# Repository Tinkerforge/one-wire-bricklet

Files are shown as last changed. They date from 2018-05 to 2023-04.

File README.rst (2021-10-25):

One Wire Bricklet
=================

This repository contains the firmware source code and the hardware design
files. The documentation generator configs can be found at
https://github.com/Tinkerforge/generators

Repository Content
------------------

software/:
 * examples/: Examples for all supported languages
 * build/: Compiled files
 * src/: Source code of firmware
 * Makefile: Makefile to build project

hardware/:
 * Contains KiCad project files and additionally schematics as PDF

datasheets/:
 * Contains datasheets for sensors and complex ICs that are used

Hardware
--------

The hardware is designed with the open source EDA Suite KiCad
(http://www.kicad.org). Before you are able to open the files,
you have to install the Tinkerforge kicad-libraries
(https://github.com/Tinkerforge/kicad-libraries). You can either clone
them directly in hardware/ or clone them in a separate folder and
symlink them into hardware/
(ln -s kicad_path/kicad-libraries project_path/hardware). After that you
can open the .pro file in hardware/ with KiCad and from there view and
modify the schematics and the PCB layout.

Software
--------

If you want to do your own Brick/Bricklet firmware development we highly
recommend that you use our build environment setup script and read the
tutorial (https://www.tinkerforge.com/en/doc/Tutorials/Tutorial_Build_Environment/Tutorial.html).

To compile the C code we recommend you to install the newest GNU Arm Embedded
Toolchain (https://launchpad.net/gcc-arm-embedded/+download).
You also need to install bricklib2 (https://github.com/Tinkerforge/bricklib2).

You can either clone it directly in software/src/ or clone it in a
separate folder and symlink it into software/src/
(ln -s bricklib_path/bricklib2 project_path/software/src/). Finally make sure to
have CMake installed (http://www.cmake.org/cmake/resources/software.html).

After that you can build the firmware by invoking make in software/.
The firmware (.zbin) can then be found in software/build/ and uploaded
with brickv (click button "Flashing" on start screen).

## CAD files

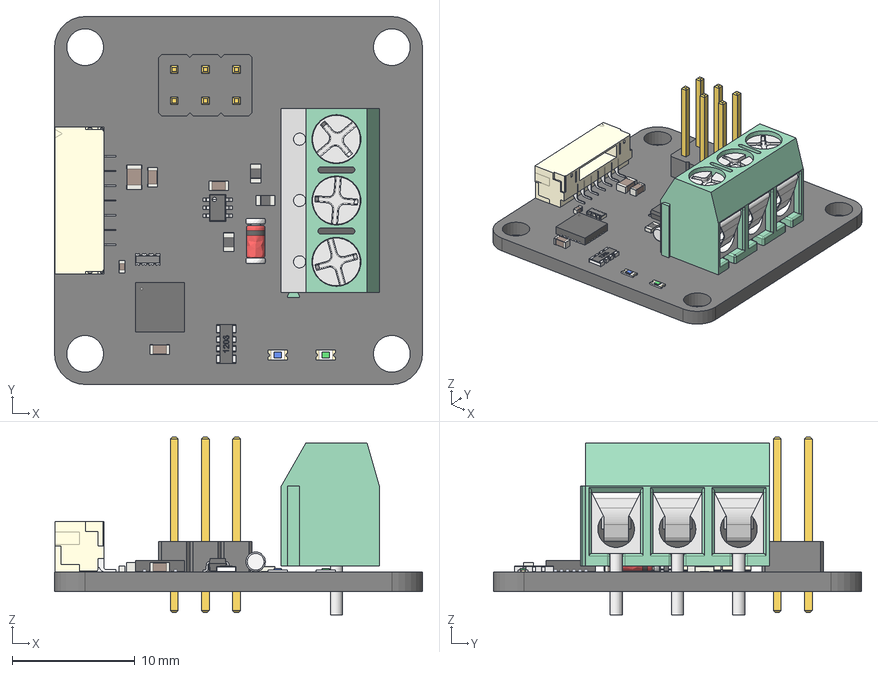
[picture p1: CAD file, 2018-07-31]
hardware/one-wire.step
30.0 x 30.0 x 14.5 mm
Pcb
QFN-24_4x4mm_Pitch0.5mm_
3er_Buchse_
User_Library-SOT363-2_
C_0805_
C_0603_
C_0603_001
D_0603_blue_
BrickletConn_7pin_
PinHeader_Straight_2x03x254mm_
R_0603_
R_0603_001
C_0603_002
R_4x0603_
C_0402_
R_0603_002
MiniMelf_

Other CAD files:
hardware/one-wire.FCStd

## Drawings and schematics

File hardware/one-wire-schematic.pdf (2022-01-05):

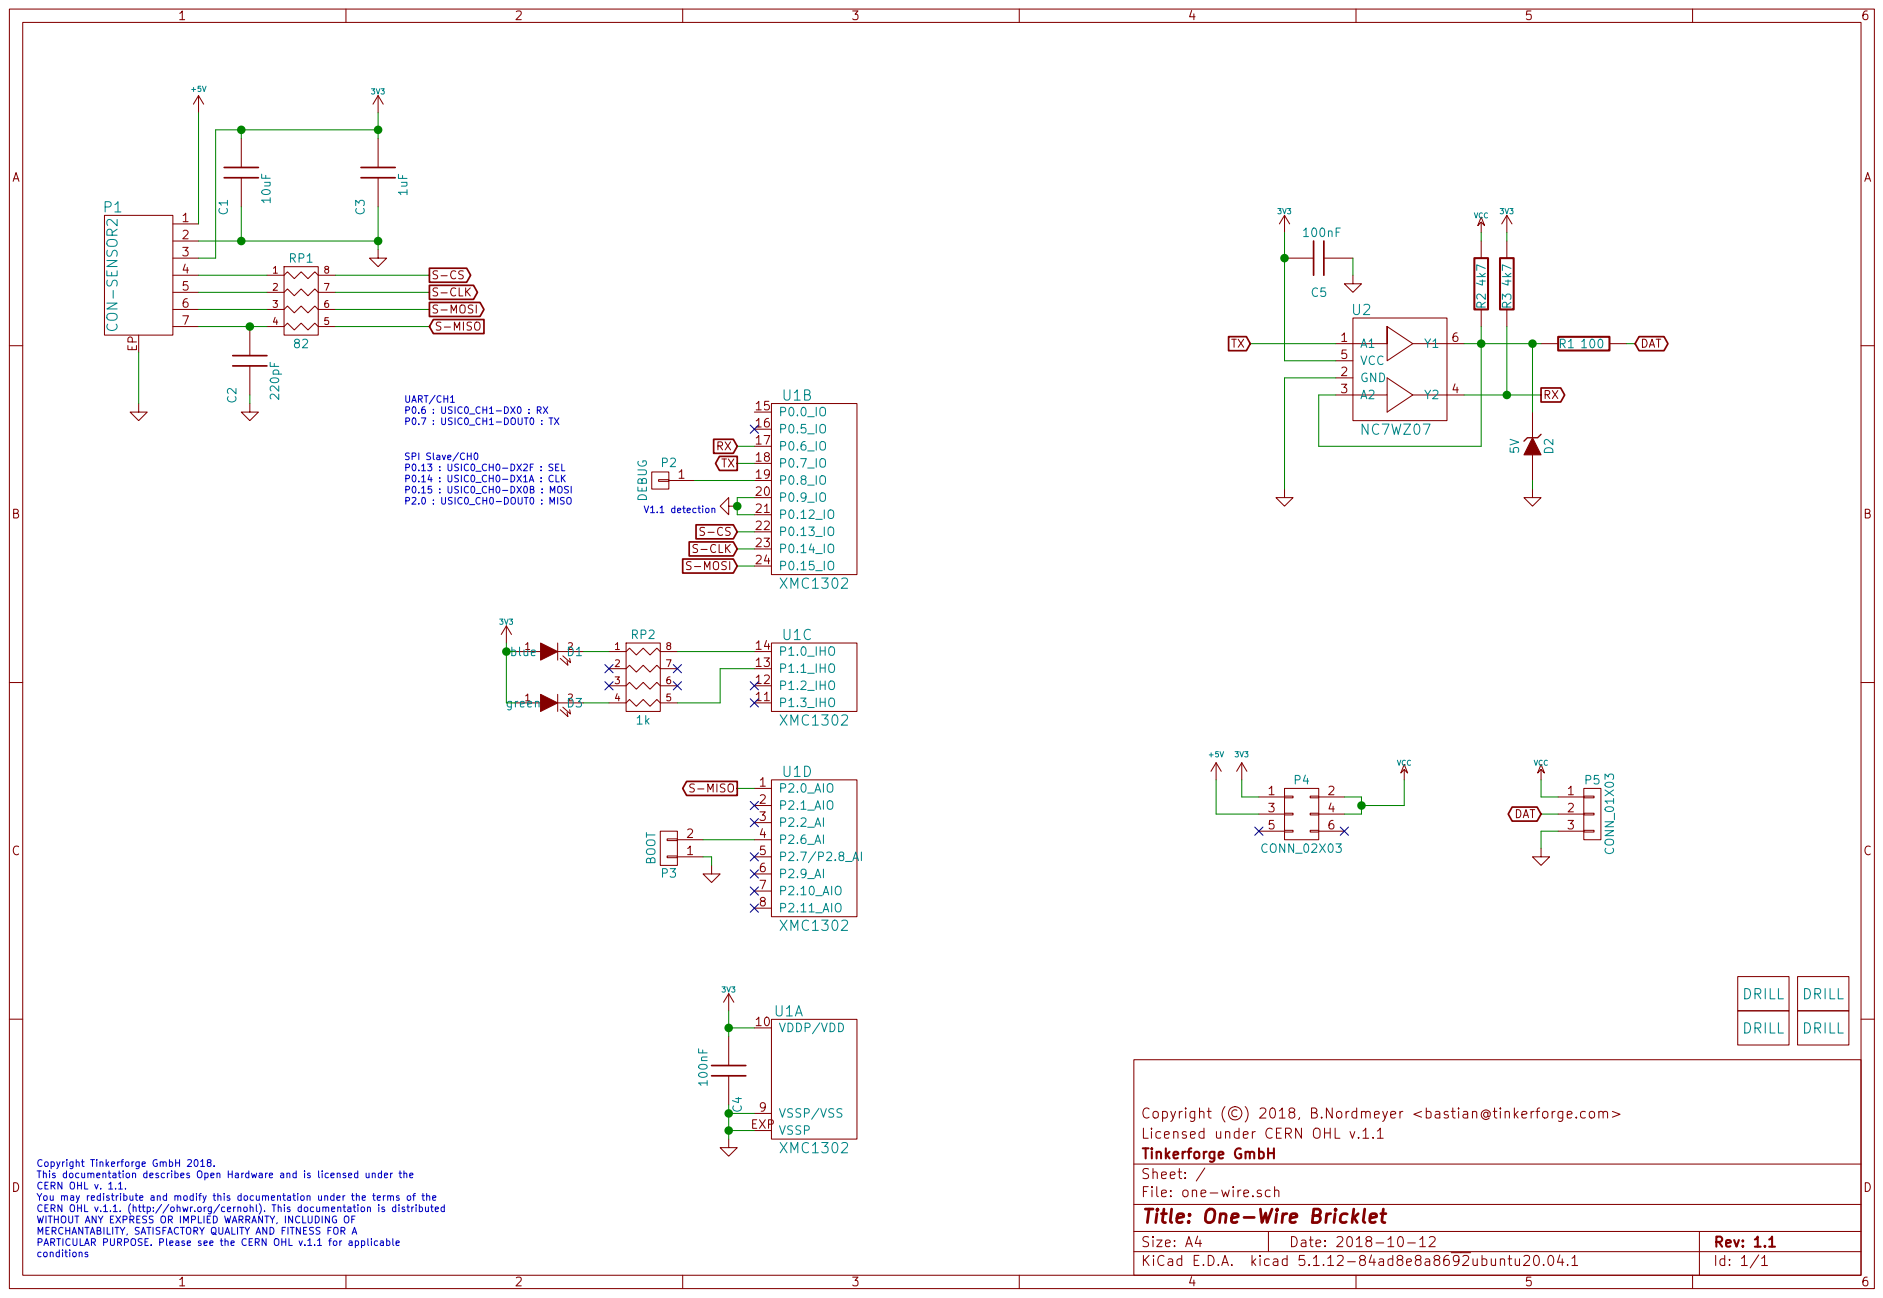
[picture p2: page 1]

Licensed under CERN OHL v.1.1 Copyright (©) 2018, B.Nordmeyer <bastian@tinkerforge.com>

Id: 1/1 Title: One-Wire Bricklet File: one-wire.sch Sheet: / Tinkerforge GmbH

Copyright Tinkerforge GmbH 2018. This documentation describes Open Hardware and is licensed under the CERN OHL v. 1.1. You may redistribute and modify this documentation under the terms of the CERN OHL v.1.1. (http://ohwr.org/cernohl). This documentation is distributed WITHOUT ANY EXPRESS OR IMPLIED WARRANTY, INCLUDING OF MERCHANTABILITY, SATISFACTORY QUALITY AND FITNESS FOR A

PARTICULAR PURPOSE. Please see the CERN OHL v.1.1 for applicable
conditions

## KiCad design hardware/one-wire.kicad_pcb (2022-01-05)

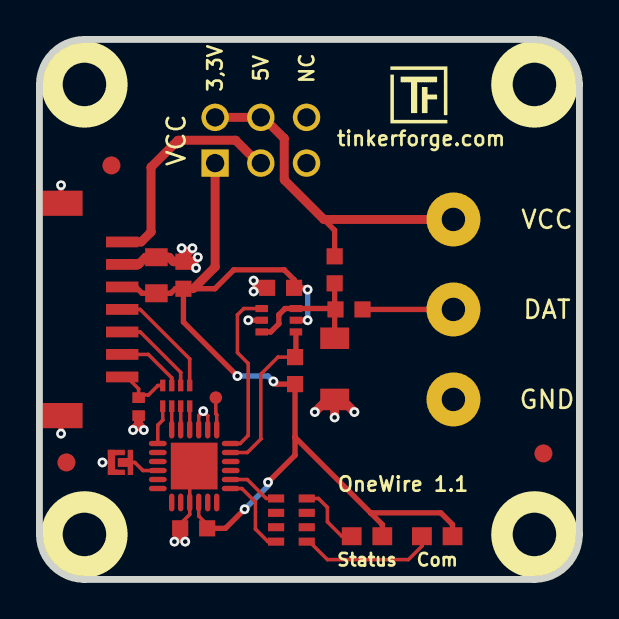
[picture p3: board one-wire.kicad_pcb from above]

Board: 2 copper layers, 30.0 x 30.0 mm, 28 parts (1 on the bottom side), 22 nets.

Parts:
C1: 10uF; C0805
C2: 220pF; C0402F
C3: 1uF; C0603F
C4, C5: 100nF; C0603F
D1: blue; D0603E
D2: 5V; MiniMelf
D3: green; D0603E
Fiducial_Mark: VAL**; Fiducial_Mark
Fiducial_Mark#2, Fiducial_Mark#3: VAL**; Fiducial_Mark
P1: CON-SENSOR2
P2: DEBUG; DEBUG_PAD
P3: BOOT; SolderJumper
P4: CONN_02X03; pin_array_3x2
P5: CONN_01X03; AKL_5_3
R1: 100; R0603F
R2, R3: 4k7; R0603F
RP1: 82; 4X0402
RP2: 1k; 4X0603
U1: XMC1302; QFN24-4x4mm-0.5mm
U2: NC7WZ07; SC70-6
U3, U4, U5, U6: DRILL; DRILL_NP
VAL: CE_5mm

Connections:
3V3: C1.2, C3.2, C4.1, C5.2, D1.1, D3.1, P1.3, P4.1, R3.1, U1.10, U2.5
+5V: P1.1, P4.3
DAT: P5.2, R1.1
GND: C1.1, C2.1, C3.1, C4.2, C5.1, D2.1, P1.2, P1.EP, P3.1, P5.3, U1.9, U1.20, U1.21, U1.EXP, U2.2
unnamed: C2.2, P1.7, RP1.4
unnamed: D1.2, RP2.1
unnamed: D2.2, R1.2, R2.2, U2.3, U2.6
unnamed: D3.2, RP2.4
unnamed: P1.4, RP1.1
unnamed: P1.5, RP1.2
unnamed: P1.6, RP1.3
unnamed: P2.1, U1.19
unnamed: P3.2, U1.4
unnamed: RP2.5, U1.13
unnamed: RP2.8, U1.14
RX: R3.2, U1.17, U2.4
S-CLK: RP1.7, U1.23
S-CS: RP1.8, U1.22
S-MISO: RP1.5, U1.1
S-MOSI: RP1.6, U1.24
TX: U1.18, U2.1
VCC: P4.2, P4.4, P5.1, R2.1

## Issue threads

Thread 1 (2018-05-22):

Onewire Bricklet

jheising, 2018-05-22:
Hi all, if it helps I've created a working onewire bricklet already at: https://github.com/jheising/onewire-bricklet. Please feel free to use in any way you want.

borg42, 2018-05-22:
Yes, we already saw it. Looks very good! The 1-Wire Bricklet will get a co-processor instead of the EEPROM (as all new Brickelts get now), so we will be able to use the UART hardware unit and implement it like this: https://www.maximintegrated.com/en/app-notes/index.mvp/id/214

We can use the UART FIFO and interrupts etc. Thus we can't unfortunately use a lot of the code that you wrote.

borg42, 2018-05-25:
The first low level stuff is now implemented and tested. We will probably add some more functions for standard 1-wire sensors like the DS18B20.

Closed 2018-05-25.

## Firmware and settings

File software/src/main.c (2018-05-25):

/* one-wire-bricklet
 * Copyright (C) 2018 Olaf Lüke <olaf@tinkerforge.com>
 *
 * main.c: Initialization for One Wire Bricklet
 *
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
 * You should have received a copy of the GNU Lesser General Public
 * License along with this library; if not, write to the
 * Free Software Foundation, Inc., 59 Temple Place - Suite 330,
 * Boston, MA 02111-1307, USA.
 */

#include <stdio.h>
#include <stdbool.h>

#include "configs/config.h"

#include "bricklib2/bootloader/bootloader.h"
#include "bricklib2/hal/system_timer/system_timer.h"
#include "bricklib2/logging/logging.h"
#include "communication.h"
#include "one_wire.h"

int main(void) {
	logging_init();
	logd("Start One Wire Bricklet\n\r");

	communication_init();
	one_wire_init();

	while(true) {
		bootloader_tick();
		communication_tick();
		one_wire_tick();
	}
}

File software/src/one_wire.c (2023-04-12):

/* one-wire-bricklet
 * Copyright (C) 2018, 2023 Olaf Lüke <olaf@tinkerforge.com>
 *
 * one_wire.c: One Wire protocol implementation
 *
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
 * You should have received a copy of the GNU Lesser General Public
 * License along with this library; if not, write to the
 * Free Software Foundation, Inc., 59 Temple Place - Suite 330,
 * Boston, MA 02111-1307, USA.
 */

#include "one_wire.h"

#include "configs/config_one_wire.h"

#include "bricklib2/os/coop_task.h"
#include "bricklib2/hal/system_timer/system_timer.h"
#include "bricklib2/logging/logging.h"

#include "communication.h"

#include <string.h>

static const uint8_t one_wire_crc_table[] = {
      0, 94,188,226, 97, 63,221,131,194,156,126, 32,163,253, 31, 65,
    157,195, 33,127,252,162, 64, 30, 95,  1,227,189, 62, 96,130,220,
     35,125,159,193, 66, 28,254,160,225,191, 93,  3,128,222, 60, 98,
    190,224,  2, 92,223,129, 99, 61,124, 34,192,158, 29, 67,161,255,
     70, 24,250,164, 39,121,155,197,132,218, 56,102,229,187, 89,  7,
    219,133,103, 57,186,228,  6, 88, 25, 71,165,251,120, 38,196,154,
    101, 59,217,135,  4, 90,184,230,167,249, 27, 69,198,152,122, 36,
    248,166, 68, 26,153,199, 37,123, 58,100,134,216, 91,  5,231,185,
    140,210, 48,110,237,179, 81, 15, 78, 16,242,172, 47,113,147,205,
     17, 79,173,243,112, 46,204,146,211,141,111, 49,178,236, 14, 80,
    175,241, 19, 77,206,144,114, 44,109, 51,209,143, 12, 82,176,238,
     50,108,142,208, 83, 13,239,177,240,174, 76, 18,145,207, 45,115,
    202,148,118, 40,171,245, 23, 73,  8, 86,180,234,105, 55,213,139,
     87,  9,235,181, 54,104,138,212,149,203, 41,119,244,170, 72, 22,
    233,183, 85, 11,136,214, 52,106, 43,117,151,201, 74, 20,246,168,
    116, 42,200,150, 21, 75,169,247,182,232, 10, 84,215,137,107, 53
};

OneWire one_wire;
CoopTask one_wire_task;

#define one_wire_rxa_irq_handler IRQ_Hdlr_13


void __attribute__((optimize("-O3"))) __attribute__ ((section (".ram_code"))) one_wire_rxa_irq_handler() {
	one_wire.error_count_parity++;

	logw("Parity Error: %d\n\r", one_wire.error_count_parity);
}


void one_wire_init_uart(void) {
	const XMC_GPIO_CONFIG_t version_detect = {
		.mode = XMC_GPIO_MODE_INPUT_PULL_UP,
		.input_hysteresis = XMC_GPIO_INPUT_HYSTERESIS_STANDARD
	};
	XMC_GPIO_Init(ONE_WIRE_VERSION_DETECTION0, &version_detect);
	XMC_GPIO_Init(ONE_WIRE_VERSION_DETECTION1, &version_detect);


	// RX pin configuration.
	const XMC_GPIO_CONFIG_t rx_pin_config = {
		.mode = XMC_GPIO_MODE_INPUT_PULL_UP,
		.input_hysteresis = XMC_GPIO_INPUT_HYSTERESIS_STANDARD
	};

	// Configure pins according to hardware version
	if(!XMC_GPIO_GetInput(ONE_WIRE_VERSION_DETECTION0) && !XMC_GPIO_GetInput(ONE_WIRE_VERSION_DETECTION1)) {
		// TX pin configuration.
		const XMC_GPIO_CONFIG_t tx_pin_config = {
			.mode = ONE_WIRE_TX11_PIN_AF,
			.output_level = XMC_GPIO_OUTPUT_LEVEL_HIGH
		};

		XMC_GPIO_Init(ONE_WIRE_RX11_PIN, &rx_pin_config);
		XMC_GPIO_Init(ONE_WIRE_TX11_PIN, &tx_pin_config);
	} else {
		// TX pin configuration.
		const XMC_GPIO_CONFIG_t tx_pin_config = {
			.mode = ONE_WIRE_TX_PIN_AF,
			.output_level = XMC_GPIO_OUTPUT_LEVEL_HIGH
		};

		XMC_GPIO_Init(ONE_WIRE_RX_PIN, &rx_pin_config);
		XMC_GPIO_Init(ONE_WIRE_TX_PIN, &tx_pin_config);
	}

	// Initialize USIC channel in UART mode.

	// USIC channel configuration.
	XMC_UART_CH_CONFIG_t config = {
        .baudrate = ONE_WIRE_BAUDRATE_RESET,
        .stop_bits = 1,
        .data_bits = 8,
        .oversampling = ONE_WIRE_OVERSAMPLING,
        .frame_length = 8,
		.parity_mode = XMC_USIC_CH_PARITY_MODE_NONE
    };

	XMC_UART_CH_Init(ONE_WIRE_USIC, &config);

	// Configure input source path according to hardware version
	if(!XMC_GPIO_GetInput(ONE_WIRE_VERSION_DETECTION0) && !XMC_GPIO_GetInput(ONE_WIRE_VERSION_DETECTION1)) {
		XMC_UART_CH_SetInputSource(ONE_WIRE_USIC, ONE_WIRE_RX11_INPUT, ONE_WIRE_RX11_SOURCE);
	} else {
		XMC_UART_CH_SetInputSource(ONE_WIRE_USIC, ONE_WIRE_RX_INPUT, ONE_WIRE_RX_SOURCE);
	}

	// Configure TX FIFO.
	XMC_USIC_CH_TXFIFO_Configure(ONE_WIRE_USIC, 32, XMC_USIC_CH_FIFO_SIZE_16WORDS, 8);

	// Configure RX FIFO.
	XMC_USIC_CH_RXFIFO_Configure(ONE_WIRE_USIC, 48, XMC_USIC_CH_FIFO_SIZE_16WORDS, 8);

	// UART protocol events.

	XMC_USIC_CH_SetInterruptNodePointer(
		ONE_WIRE_USIC,
		XMC_USIC_CH_INTERRUPT_NODE_POINTER_ALTERNATE_RECEIVE,
		ONE_WIRE_SERVICE_REQUEST_RXA
	);

	// Set priority and enable NVIC node for RXA interrupt.
	NVIC_SetPriority((IRQn_Type)ONE_WIRE_IRQ_RXA, ONE_WIRE_IRQ_RXA_PRIORITY);
	NVIC_EnableIRQ((IRQn_Type)ONE_WIRE_IRQ_RXA);

	// Restart UART: Stop.
	while(XMC_UART_CH_Stop(ONE_WIRE_USIC) != XMC_UART_CH_STATUS_OK);

	// Restart UART: Start.
	XMC_UART_CH_Start(ONE_WIRE_USIC);

	XMC_USIC_CH_EnableEvent(ONE_WIRE_USIC, XMC_USIC_CH_EVENT_ALTERNATIVE_RECEIVE);
}

uint8_t one_wire_task_transceive_uart_byte(uint8_t byte) {
	XMC_USIC_CH_RXFIFO_Flush(ONE_WIRE_USIC);
	ONE_WIRE_USIC->IN[0] = byte;

	uint32_t t = system_timer_get_ms();
	while(XMC_USIC_CH_RXFIFO_IsEmpty(ONE_WIRE_USIC)) {
		coop_task_yield();
		if(system_timer_is_time_elapsed_ms(t, 250)) {
			one_wire.response_status = ONE_WIRE_STATUS_TIMEOUT;
		}
	}

	return ONE_WIRE_USIC->OUTR;
}

bool one_wire_task_bit(bool value) {
	uint8_t bit = one_wire_task_transceive_uart_byte(value ? 0xFF : 0x00);
	return bit == 0xFF;
}

uint8_t one_wire_task_byte(uint8_t value) {
	led_flicker_increase_counter(&one_wire.com_led_state);

	uint8_t ret = 0;
	for(uint8_t i = 0; i < 8; i++) {
		ret |= one_wire_task_bit(value & (1 << i)) << i;
		if(one_wire.response_status == ONE_WIRE_STATUS_TIMEOUT) {
			return 0;
		}
	}

	return ret;
}
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

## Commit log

2018-05-07 Add schematic
    [one-wire.sch]
2018-05-07 fix rx schematic
    [one-wire.sch]
2018-05-07 Add another led
    [one-wire.sch]
2018-05-07 Assign footprints
    [one-wire.sch]
2018-05-07 Assign missing footprint
    [one-wire.sch]
2018-05-07 Add layout (tbc)
    [one-wire.kicad_pcb]
2018-05-08 one wire bricklet fully routed
    [one-wire.kicad_pcb, one-wire.sch]
2018-05-11 Change 3d model color
    [one-wire.kicad_pcb]
2018-05-17 add z diode hint
    [one-wire.kicad_pcb]
2018-05-18 Add stub firmware for One Wire Bricklet
    [cmake_config_custom.txt]
2018-05-25 Add 1-wire API and implementation
2018-05-25 Change MCU from XMC11 to XMC13, so we have more flash for future functions. We might want to add functions like "temperature_read_ds18b20" and it is currently unclear how many of those functions we w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
    With XMC11 we would have only ~2kb left, with XMC13 we have 18kb left!
    [cmake_config_custom.txt]
2018-05-25 Change baudrate with precomputed values, the computation in the SetBaudrate function is way too slow
    [one_wire.c]
2018-06-06 set origin, specify zener
    [one-wire.kicad_pcb, one-wire.sch]
2018-06-18 Change capacitor footprint(s) to C0402F
    [one-wire.kicad_pcb, one-wire.sch]
2018-07-17 respecify processor XMC1100 -> 1300
    [one-wire.kicad_pcb, one-wire.sch]
2018-07-30 change protection diode to minimelf
    [one-wire.kicad_pcb, one-wire.sch]
2018-07-31 Add 3d model (*.FCStd & *.step)
    [one-wire.FCStd, one-wire.step]
2018-09-11 Complete partially auto-generated Mathematica example
    This is currently untested
2018-09-27 examples: Fix compile errors and unify style
    [example_read_ds18b20_temperature.c]
2018-10-10 fix one wire routing
    [one-wire.kicad_pcb, one-wire.sch]
2018-10-12 increase hardware version to 1.1
    * previous fixed (rx,tx moved) will be used
    * add version detection pins (gnd)
    * increase version number
    [one-wire.kicad_pcb, one-wire.sch]
2018-12-19 Fix two's complement handling in DS18B20 example.
    [example_read_ds18b20_temperature.c]
2019-01-29 Clean up style and fix some minor problems in examples
    [example_read_ds18b20_temperature.c]
2020-08-31 uc: Use fixed-with placeholders in format strings.
    [example_read_ds18b20_temperature.c]
2020-09-02 uc: Add example driver note.
2021-10-25 Update KiCad link
    https://www.kicad.org/blog/2021/10/Avoid-links-to-former-kicad-domain/
2022-01-05 specify processor xmc1302
    [one-wire.kicad_pcb, one-wire.sch]
2022-04-26 uc: Adapt to bindings changes
    [example_read_ds18b20_temperature.c]

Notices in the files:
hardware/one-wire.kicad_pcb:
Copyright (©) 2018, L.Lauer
